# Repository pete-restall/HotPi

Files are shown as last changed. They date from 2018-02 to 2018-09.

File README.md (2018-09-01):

# HotPi - A Pi Zero W Reflow Oven Controller

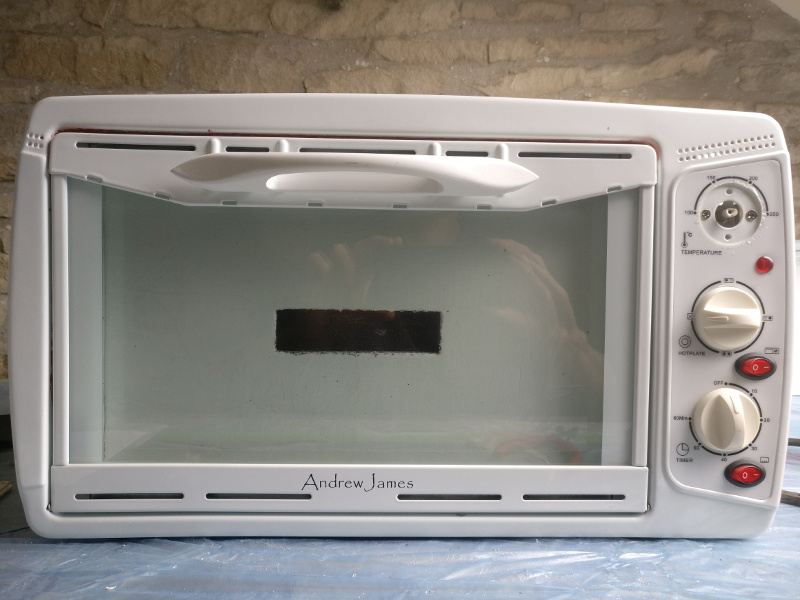
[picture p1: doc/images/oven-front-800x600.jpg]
The Oven


## What is it ?
Years ago I bought a small oven for reflow conversion but never really got
around to it.  More recently I've had a need to reflow boards more accurately
than I can do 'by eye' so I decided to make some time and throw something
together using mainly bits I have to hand.

A &pound;9 Pi Zero W, an old project box that's probably older than I am, some
jellybean parts lying in my junk box, some nice 480V 25A SSRs I bought at the
same time as the oven, coupled with a few other cheap bits and pieces like an
open frame Mean Well IRM-10-5 5V 2A flyback converter should suffice.  Nothing
fancy, no bells and whistles.

The PCB was intended to be milled as it should have been a quicker turnaround
and cheaper since I have the copper clad and engraving bits already, although it
is much more labour intensive than outsourcing to China.  Unfortunately the
resolution required to mill the features of the MAX31850 was insufficient.

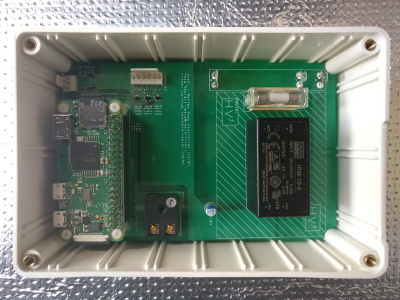
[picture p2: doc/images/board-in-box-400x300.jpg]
The Board


This is a personal one-off project and not intended for anybody else's
consumption.  But in case somebody's tempted then the usual disclaimers about
playing with mains voltages apply...

## Software
I had started off writing the software myself but it was turning out to be
a larger job than I wanted.  Then I stumbled across
[picoReflow](https://github.com/apollo-ng/picoReflow).  I spent a few hours
hacking some Python and ended up with a fully functional reflow controller
and UI in a fraction of the time it would take to roll my own.  Thanks !

The MAX31850 communication is a hand-cranked user-space bit-banging library
based around [BCM2835](http://www.airspayce.com/mikem/bcm2835/), basically
because there is no kernel support for the MAX31850 via the w1 module (and
the fallback w1-gpio is not good enough).

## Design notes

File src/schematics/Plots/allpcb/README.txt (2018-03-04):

Customer:
---------
Pete Restall (Parity Computer Consultancy Limited) - pete@restall.net
Any problems / questions, please do not hesitate to get in touch.

Design Tools Used:
------------------
DesignSpark 8.0
GC-Prevue 25.3.6

Track and Spacing:
------------------
Minimum 8mil.

Layers:
-------
All viewed from above, no mirroring.  Solder Resist layers are negatives, all
others are positives.

Board Outline:
--------------
All layers contain a zero-width board outline.  Outline size is
5.510in x 3.542in and >= 8mil from any feature, copper or otherwise.

Vias and Silkscreen:
--------------------
Some vias are partially covered with silkscreen; this is not anticipated to
be an issue since they should be tented.

Pads and Silkscreen:
--------------------
Some silkscreen overlaps (ie. in the hatched area), but this is not an issue.
The silkscreen can be clipped where necessary, but please advise if this is
going to be an issue.

Drill Holes:
------------
All are through-plated and are finished sizes; no adjustments have been made
for plating thickness.  All are >= 10mil from the edge of the board.

Bit sizes can be rounded to the nearest 0.1mm.  Please advise if any drill
sizes are found to be incompatible with your processes.

Annular rings >= 8mil.

Data Formats:
-------------
More detailed information can be found in "DesignSpark Plot Report.TXT", but
in summary:

---------------
Gerber Settings
---------------

    Leading zero suppression.
    G01 assumed throughout.
    Line termination <*> <CR> <LF>.
    3.5 format absolute inches.
    Format commands defined in Gerber file.
    Aperture table defined in Gerber file.
    Hardware arcs allowed.

--------------
Drill Settings
--------------

    Excellon Format 1
    Format 3.5 absolute in inches.
    No zero suppression.

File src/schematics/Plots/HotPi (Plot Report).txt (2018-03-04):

Plot Report
-----------

Report Written:     Sunday, March 04, 2018
Project Path:       Z:\home\pete\Projects\HotPi\src\schematics\HotPi.prj
Design Path:        Z:\home\pete\Projects\HotPi\src\schematics\HotPi.pcb
Design Title:       
Created:            13/02/2018 10:54:05
Last Saved:         04/03/2018 13:51:20
Editing Time:       3486 min
Units:              mil (precision 0)

Device Settings
===============

Gerber Settings
===============

    Leading zero suppression.
    G01 assumed throughout.
    Line termination <*> <CR> <LF>.
    3.5 format absolute inches.

    Format commands defined in Gerber file.
    Aperture table defined in Gerber file.
    Hardware arcs allowed.

Drill Settings
==============

    Excellon Format 1    Format 3.5 absolute in inches.
    No zero suppression.

Plots Output
============

    Plot Job: "Z:\home\pete\Projects\HotPi\src\schematics\HotPi.mop"

Gerber Output
=============

Z:\home\pete\Projects\HotPi\src\schematics\Plots\HotPi - Top Silkscreen.gbr

    Layers:
    ------------------
    Top Silkscreen
    Board Outlines

    D-Code Shape  (thou)
    -----------------------
    D10    Round 5.00
    D12    Round 10.00
    D109   Round 12.00
    D125   Round 7.87

Gerber Output
=============

Z:\home\pete\Projects\HotPi\src\schematics\Plots\HotPi - Top Copper.gbr

    Layers:
    ------------------
    Top Copper
    Board Outlines

    D-Code Shape  (thou)
    ----------------------------------------------
    D12    Round 10.00
    D18    Oval 60.00 X 110.00  Rotation 90
    D20    Square 68.00
    D28    Rectangle 28.00 X 35.00
    D29    Rectangle 28.00 X 35.00  Rotation 90
    D76    Round 25.00
    D109   Round 12.00
    D110   Round 1.00
    D111   Rectangle 30.71 X 30.71  Rotation 90
    D112   Round 137.80
    D113   Round 110.24
    D114   Round 220.47
    D115   Round 129.92
    D117   Rectangle 25.00 X 80.00  Rotation 90
    D118   Rectangle 49.21 X 78.74  Rotation 90
    D119   Square 76.00
    D120   Round 64.00
    D123   Round 50.00
    D124   Round 157.48
    D126   Round 59.06

Gerber Output
=============

Z:\home\pete\Projects\HotPi\src\schematics\Plots\HotPi - Top Copper (Resist).gbr

    Layers:
    ------------------
    Top Copper
    Board Outlines

    D-Code Shape  (thou)
    ----------------------------------------------
    D82    Oval 70.00 X 120.00  Rotation 90
    D86    Square 78.00
    D94    Rectangle 38.00 X 45.00
    D95    Rectangle 38.00 X 45.00  Rotation 90
    D109   Round 12.00
    D127   Rectangle 40.71 X 40.71  Rotation 90
    D128   Round 147.80
    D129   Round 120.24
    D130   Round 230.47
    D131   Round 139.92
    D132   Round 69.06
    D133   Rectangle 35.00 X 90.00  Rotation 90
    D134   Rectangle 59.21 X 88.74  Rotation 90
    D135   Square 86.00
    D136   Round 167.48

Gerber Output
=============

Z:\home\pete\Projects\HotPi\src\schematics\Plots\HotPi - Bottom Silkscreen.gbr

    Layers:
    ---------------------
    Bottom Silkscreen
    Board Outlines

    D-Code Shape  (thou)
    -----------------------
    D10    Round 5.00
    D109   Round 12.00

Gerber Output
=============

Z:\home\pete\Projects\HotPi\src\schematics\Plots\HotPi - Bottom Copper.gbr

    Layers:
    ------------------
    Bottom Copper
    Board Outlines

    D-Code Shape  (thou)
    -----------------------------------------------
    D12    Round 10.00
    D18    Oval 60.00 X 110.00  Rotation 90
    D20    Square 68.00
    D24    Rectangle 55.00 X 60.00
    D28    Rectangle 28.00 X 35.00
    D29    Rectangle 28.00 X 35.00  Rotation 90
    D76    Round 25.00
    D108   Round 100.00
    D109   Round 12.00
    D110   Round 1.00
    D112   Round 137.80
    D113   Round 110.24
    D114   Round 220.47
    D115   Round 129.92
    D119   Square 76.00
    D120   Round 64.00
    D121   Rectangle 11.81 X 31.10  Rotation 90
    D122   Rectangle 90.55 X 102.36  Rotation 90
    D124   Round 157.48
    D126   Round 59.06

Gerber Output
=============

Z:\home\pete\Projects\HotPi\src\schematics\Plots\HotPi - Bottom Copper (Resist).gbr

    Layers:
    ------------------
    Bottom Copper
    Board Outlines

    D-Code Shape  (thou)
    ------------------------------------------------
    D82    Oval 70.00 X 120.00  Rotation 90
    D86    Square 78.00
    D90    Rectangle 65.00 X 70.00
    D94    Rectangle 38.00 X 45.00
    D95    Rectangle 38.00 X 45.00  Rotation 90
    D109   Round 12.00
    D128   Round 147.80
    D129   Round 120.24
    D130   Round 230.47
    D131   Round 139.92
    D132   Round 69.06
    D135   Square 86.00
    D136   Round 167.48
    D137   Rectangle 21.81 X 41.10  Rotation 90
    D138   Rectangle 100.55 X 112.36  Rotation 90

NC Drill Output
===============

Z:\home\pete\Projects\HotPi\src\schematics\Plots\HotPi - Drill Data - [Through Hole].drl

    Output:
    ---------------------------
    Plated Round Drill Holes
    Plated Slots

    Tool  Size         Count   ID
    ------------------------------------
    T001  000.02756 in 4     Y
    T002  000.03200 in 41    D
    T003  000.03937 in 40    C
    T004  000.04300 in 9     X
    T005  000.04331 in 4     F
    T006  000.05118 in 2     U
    T007  000.05512 in 2     V
    T008  000.05906 in 6     N
    T009  000.11024 in 1     W
    ------------------------------------
    Total              109
    ------------------------------------

Z:\home\pete\Projects\HotPi\src\schematics\Plots\HotPi - Drill Data - [Through Hole] (Unplated).drl

    Output:
    -----------------------------
    Unplated Round Drill Holes
    Unplated Slots
    Unplated Board Outlines

    Tool  Size         Count   ID
    ------------------------------------
    T001  000.02500 in 1
    T002  000.11024 in 4     Q
    ------------------------------------
    Total              5
    ------------------------------------

Gerber Output
=============

Z:\home\pete\Projects\HotPi\src\schematics\Plots\HotPi - Drill Ident Drawing - [Through Hole].gbr

    Layers:
    ------------------
    [Through Hole]
    Board Outlines

Drill Ident Drawing
===================

    Drill Plated Size Shape ID
    -----------------------------------
    39    Y      100  Round C
    32    Y      100  Round D
    43    Y      100  Round F
    59    Y      100  Round N
    110          100  Round Q
    51    Y      100  Round U
    55    Y      100  Round V
    110   Y      100  Round W
    43    Y      100  Round X
    28    Y      100  Round Y

    D-Code Shape  (thou)
    -----------------------
    D10    Round 5.00
    D108   Round 100.00
    D109   Round 12.00

Gerber Output
=============

Z:\home\pete\Projects\HotPi\src\schematics\Plots\HotPi - Board Outline.gbr

    Layers:
    ------------------
    Board Outlines

    D-Code Shape  (thou)
    -----------------------
    D109   Round 12.00

End Of Report.

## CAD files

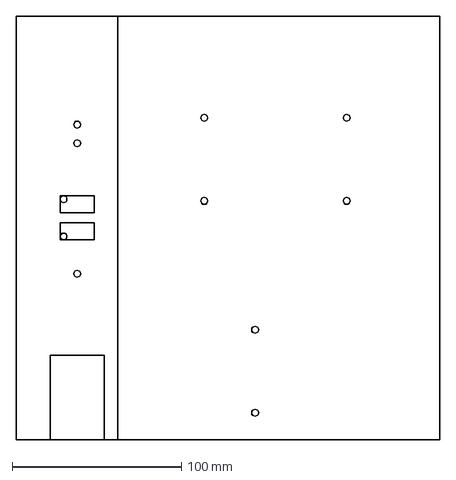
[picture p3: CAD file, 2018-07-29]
src/cnc/SsrMount.dxf
250.0 x 250.0 mm

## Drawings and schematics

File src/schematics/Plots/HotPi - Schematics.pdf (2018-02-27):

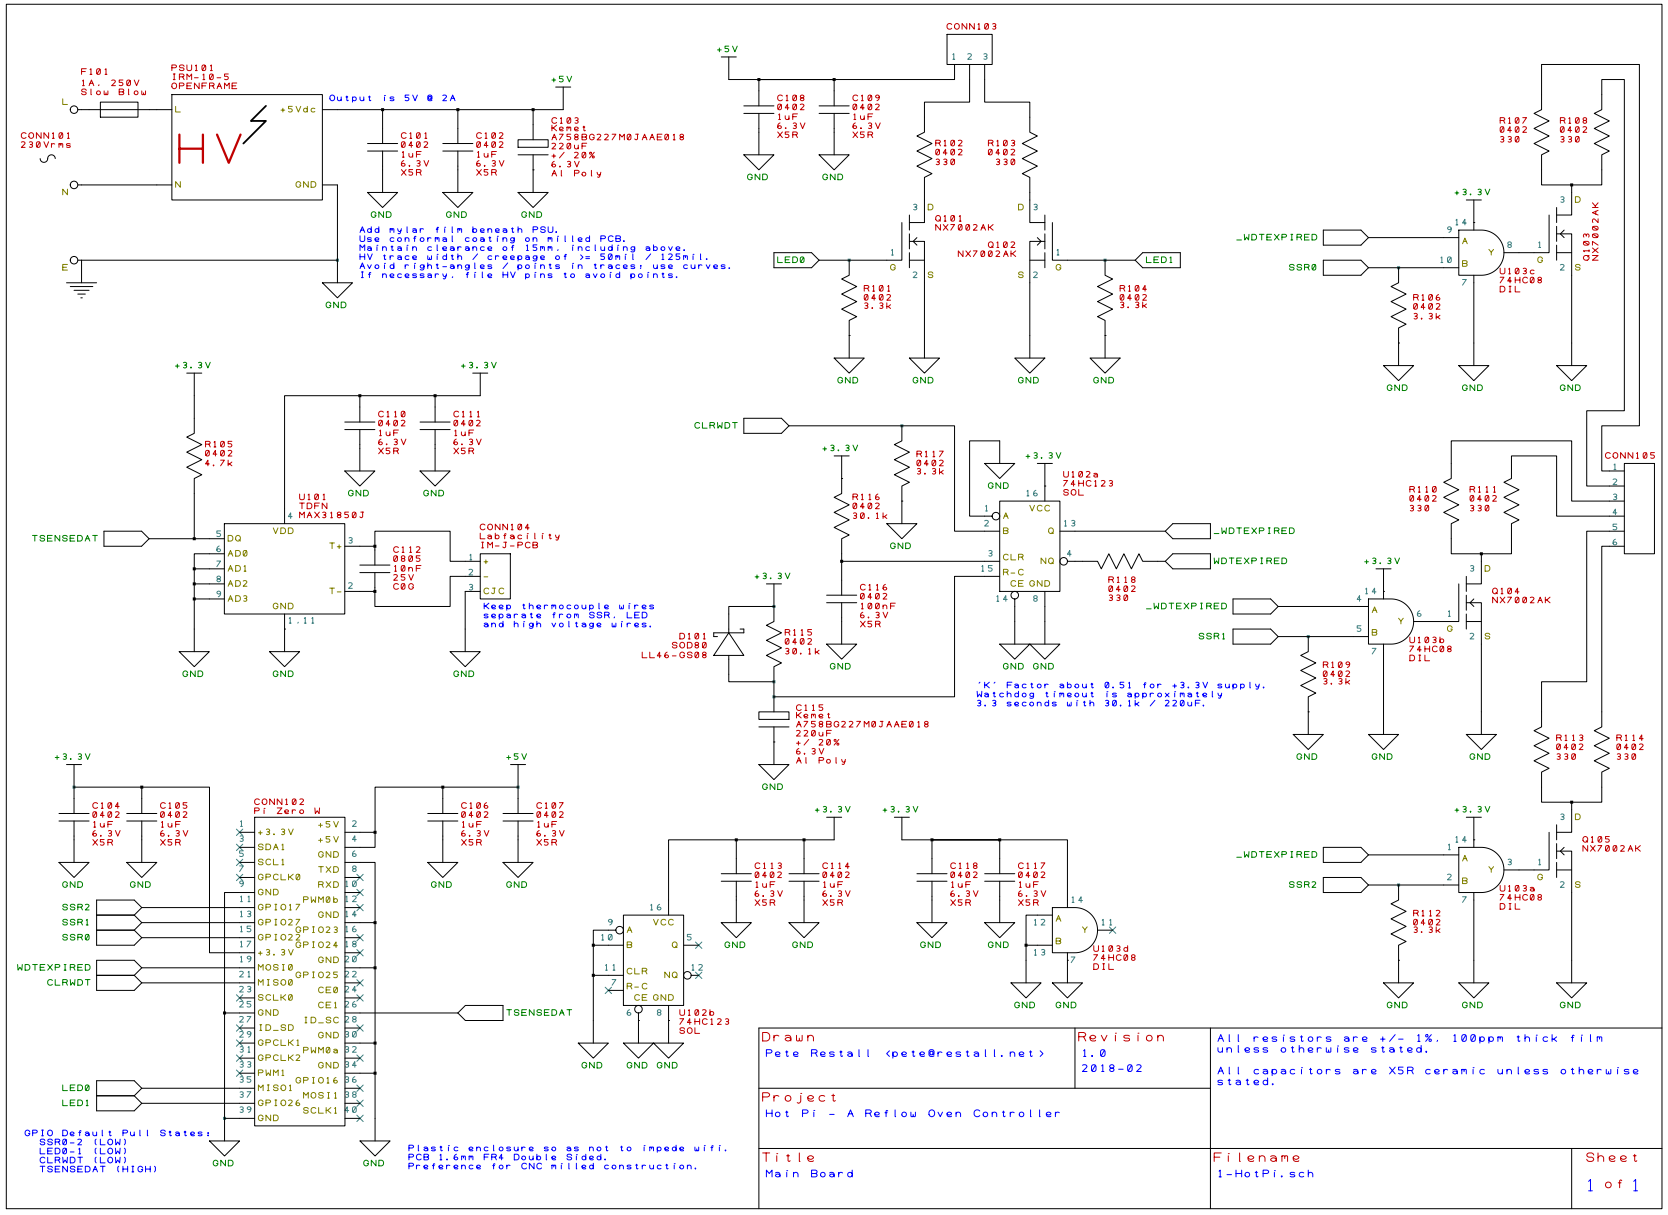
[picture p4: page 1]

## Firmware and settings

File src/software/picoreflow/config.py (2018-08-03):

import logging

########################################################################
#
#   General options

### Logging
log_level = logging.INFO
log_format = '%(asctime)s %(levelname)s %(name)s: %(message)s'

### Server
listening_ip = "0.0.0.0"
listening_port = 80

### Cost Estimate
kwh_rate        = 0.20  # Rate in currency_type to calculate cost to run job
currency_type   = "GBP"   # Currency Symbol to show when calculating cost to run job

########################################################################
#
#   GPIO Setup (BCM SoC Numbering Schema)
#
#   Check the RasPi docs to see where these GPIOs are
#   connected on the P1 header for your board type/rev.
#   These were tested on a Pi B Rev2 but of course you
#   can use whichever GPIO you prefer/have available.

### Outputs
gpio_heat_top = 27     # Switches zero-cross solid-state-relay
gpio_heat_bottom = 22  # Switches zero-cross solid-state-relay
gpio_cool = 19         # Regulates PWM for 12V DC Blower
gpio_air  = 17         # Switches 0-phase det. solid-state-relay
gpio_clrwdt = 9        # A pulse clears the watchdog timer
heater_invert = 0      # switches the polarity of the heater control

### Inputs
gpio_door = 18

### Thermocouple Adapter selection:
#   max31855 - bitbang SPI interface
#   max31855spi - kernel SPI interface
#   max6675 - bitbang SPI interface
max31855 = 0
max6675 = 0
max31855spi = 0 # if you use this one, you MUST reassign the default GPIO pins
hotpi = 1

### Thermocouple Connection (using bitbang interfaces)
gpio_sensor_cs = 27
gpio_sensor_clock = 22
gpio_sensor_data = 17

### Thermocouple SPI Connection (using adafrut drivers + kernel SPI interface)
spi_sensor_chip_id = 0

### amount of time, in seconds, to wait between reads of the thermocouple
sensor_time_wait = .2


########################################################################
#
#   PID parameters

pid_ki = 0.1  # Integration
pid_kd = 0.4  # Derivative
pid_kp = 0.5  # Proportional


########################################################################
#
#   Simulation parameters

sim_t_env      = 25.0   # deg C
sim_c_heat     = 100.0  # J/K  heat capacity of heat element
sim_c_oven     = 2000.0 # J/K  heat capacity of oven
sim_p_heat     = 3500.0 # W    heating power of oven
sim_R_o_nocool = 1.0    # K/W  thermal resistance oven -> environment
sim_R_o_cool   = 0.05   # K/W  " with cooling
sim_R_ho_noair = 0.1    # K/W  thermal resistance heat element -> oven
sim_R_ho_air   = 0.05   # K/W  " with internal air circulation


########################################################################
#
#   Time and Temperature parameters

temp_scale          = "c" # c = Celsius | f = Fahrenheit - Unit to display 
time_scale_slope    = "s" # s = Seconds | m = Minutes | h = Hours - Slope displayed in temp_scale per time_scale_slope
time_scale_profile  = "s" # s = Seconds | m = Minutes | h = Hours - Enter and view target time in time_scale_profile

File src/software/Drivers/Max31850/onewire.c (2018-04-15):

#include <bcm2835.h>

#include "onewire.h"

#define MAX_RISE_TIME_US 2
#define MIN_PULSE_US 2
#define RECOVERY_US (MAX_RISE_TIME_US + 2)

static const RPiGPIOPin onewire = RPI_GPIO_P1_26;

static void onewireTristate(void);
static void onewireDriveLow(void);
static int onewireIsLow(void);
static void onewireWriteBit(unsigned char bit);

int NOEXPORT onewireInitialise(void)
{
	if (!bcm2835_init())
		return ERROR_INIT_BCM2835;

	bcm2835_gpio_set_pud(onewire, BCM2835_GPIO_PUD_OFF);
	onewireTristate();

	return ERROR_NONE;
}

static void onewireTristate(void)
{
	bcm2835_gpio_fsel(onewire, BCM2835_GPIO_FSEL_INPT);
}

void NOEXPORT onewireShutdown(void)
{
	bcm2835_close();
}

int NOEXPORT onewireReset(void)
{
	onewireDriveLow();
	bcm2835_delayMicroseconds(490);
	onewireTristate();
	bcm2835_delayMicroseconds(70);
	if (!onewireIsLow())
		return ERROR_NO_PRESENCE_PULSE;

	bcm2835_delayMicroseconds(460);
	if (onewireIsLow())
		return ERROR_PRESENCE_PULSE_TOO_LONG;

	return ERROR_NONE;
}

static void onewireDriveLow(void)
{
	bcm2835_gpio_clr(onewire);
	bcm2835_gpio_fsel(onewire, BCM2835_GPIO_FSEL_OUTP);
}

static int onewireIsLow(void)
{
	return bcm2835_gpio_lev(onewire) == LOW;
}

void NOEXPORT onewireWriteSkipRom(void)
{
	onewireWriteByte(0xcc);
}

void NOEXPORT onewireWriteByte(unsigned char byte)
{
	for (int i = 0; i < 8; i++)
	{
		onewireWriteBit(byte & 0x01);
		byte >>= 1;
	}
}

static void onewireWriteBit(unsigned char bit)
{
	onewireDriveLow();
	if (bit == 0)
	{
		bcm2835_delayMicroseconds(61);
		onewireTristate();
		bcm2835_delayMicroseconds(MAX_RISE_TIME_US + RECOVERY_US);
	}
	else
	{
		bcm2835_delayMicroseconds(MIN_PULSE_US);
		onewireTristate();
		bcm2835_delayMicroseconds(
			61 - MIN_PULSE_US + MAX_RISE_TIME_US + RECOVERY_US);
	}
}

unsigned char NOEXPORT onewireReadByte(void)
{
	unsigned char byte = 0;
	for (unsigned char i = 0; i < 8; i++)
		byte |= (unsigned char) (onewireReadBit() << i);

	return byte;
}

unsigned char NOEXPORT onewireReadBit(void)
{
	unsigned char bit;
	onewireDriveLow();
	bcm2835_delayMicroseconds(MIN_PULSE_US);
	onewireTristate();
	bcm2835_delayMicroseconds(MAX_RISE_TIME_US + 8);
	bit = onewireIsLow() ? 0 : 1;
	bcm2835_delayMicroseconds(
		60 - MAX_RISE_TIME_US - 8 - MIN_PULSE_US + RECOVERY_US);

	return bit;
}

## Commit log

2018-02-27 Initial commit.
    [1-HotPi.sch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]
2018-03-04 Inadequate CNC resolution so outsourcing to China...
    [HotPi - Bottom Copper (Resist).gbr, HotPi - Bottom Copper.gbr, HotPi - Bottom Silkscreen.gbr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]
2018-03-09 Wired the skeleton Angular project into the application.
2018-03-11 Added a basic stub ECharts page for the temperature chart.
2018-03-11 Switched from Nancy Self Hosting to OWIN in preparation for using SignalR.
2018-03-14 Added skeleton SignalR infrastructure and wired it up.
2018-03-15 Wired the SignalR event stream into the ECharts.
2018-03-19 Hacked together a dirty driver for the MAX31850, necessary because of its sensitivity to pulse timing. This will need to be invoked from a single thread that is scheduled at a near-realtime priority.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
    [onewire.c]
2018-03-20 Shared Object amendments - symbol visibility fix, compiler optimisations and also committing the binary so that it can be referenced by the .NET solution.
    [onewire.c]
2018-03-22 Added a basic button to the UI to start the Reflow process.
2018-03-23 Wired up a 'START /reflow' REST call. And changed the Pi shutdown call to 'SHUTDOWN /pi'.
2018-03-30 1-wire data needs to be read LSb first. Also increased the 1-wire sample time by 2us to give the MAX31850 more time to respond and pull low.
2018-03-30 Missing the 1-wire 'Skip ROM' command so the MAX31850 was not responding to the function commands.
    [onewire.c]
2018-04-02 Started to play around with and build PID infrastructure.
2018-04-02 Proper temperature conversion / compensation using the (now correct !) NIST J thermocouple inverse coefficients. Moved the oven-specific stuff into its own namespace.
2018-04-14 Made a good start on the reflow controller (UI down to the PID controller, but nothing reacting to the PID output yet - no actuators).
2018-04-15 Incorrect WDT expiry wired into SignalR.
2018-04-15 Tweaked the OneWire timings slightly - bit errors reduced a little but not greatly.
    [onewire.c]
2018-04-16 Wired the actuators (SSRs controlling the oven elements) into the PIPD controller.
2018-06-02 Added the CNC programs for the SSR mounting bracket. Added the KSIM380D25-L SSR datasheet since I couldn't find the relays I intended to use. Added the NX7002AK datasheet as it was missing.
    [SsrMount.dxf]
2018-07-29 Assigned the correct SSRs to the elements based on the physical wiring.
2018-07-29 Added a fan actuator - this is always on when the WDT is not expired. Hacked in an over-temperature check for safety (>= 270 Celsius).
2018-08-03 Added picoReflow as a replacement for the .NET reflow controller I was hand-rolling. Much quicker to adapt an existing chunk of Python than roll my own controller and UI.
    [config.py, picoreflowd.py]
2018-09-01 Added a couple of images of the oven.
2018-09-01 Added a couple of images to the README.
